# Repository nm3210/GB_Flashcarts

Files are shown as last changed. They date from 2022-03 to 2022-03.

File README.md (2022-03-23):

# GB Flashcarts

## MBC5 Short
*Uploaded to OshPark: https://oshpark.com/shared_projects/A7b5nxHa*

MBC5 Short Front in OshPark purple&nbsp;MBC5 Short Back in OshPark purple
MBC5 Short Front&nbsp;MBC5 Short Back

This is my first try (plus updates) at routing the short version of an MBC5 flashcart, there certainly wasn't a lot of room!

Heavily inspired by [**HDR**](https://martinrefseth.com/)'s [updated MBC3](https://oshpark.com/shared_projects/YCtVNv4A) cart with clean borders and neat original/OEM features like the production date squares and (totally unnecessary) fiducial markings, as well as his own older [short MBC5 cart](https://oshpark.com/shared_projects/IOwfD0lC).

### Board features

\- GameBoy_GamePak_AGB-002 template from [github.com/**djedditt**/kicad-gamepaks](https://github.com/djedditt/kicad-gamepaks) (though I had to change all the rear shapes into netted pads)

\- Schematic mostly from [github.com/**HDR**/MBC5-Flashcart](https://github.com/HDR/MBC5-Flashcart)

\- Date markings and fiducials directly from [github.com/**HDR**/MBC3-Flashcart](https://github.com/HDR/MBC3-Flashcart) (though I tweaked the size a bit)

\- Some labels done via [github.com/gregdavill/KiBuzzard](https://github.com/gregdavill/KiBuzzard)

\- No traces connecting to the cart connector pins on the back side of the board, with a ground plane buffer - this seems to be a 'feature' on a lot of the OEM MBC3/MBC5 nintendo gameboy cartidges I've seen, though I don't know why. This restricted the routing on the board quite a bit!

### Bill of Materials
*Note*: need to order at a 0.8mm service (see OshPark's ["**2oz-0.8mm**"](https://docs.oshpark.com/services/two-layer-hhdc/)) for it to actually fit in a cart slot

| Reference | Part |
| :-- | :--: |
| U1 | TSOP-40/TSOP-48 MBM29F033C-90PTN, AM29F016B-90EC, or similar |
| U2 | MBC5 (from donor cart?) |
| U3 | 28-pin SOIC FM18W08 |
| C# | 100nF Capacitor 0603 |

### Changelog
\- **v1** around 2022-03-12

&emsp;First release, hoping for the best

\- **v2** around 2022-03-22

&emsp;Change from TSOP-40 to TSOP-48 to allow for more chip variants (including ones I bought of course)

&emsp;Fixed **wrong corner** marker on U1 (from lower-left to upper-right, specifically: the side with the **W**rite**E**nable pin should be facing south)

&emsp;Minor routing updates/cleanup

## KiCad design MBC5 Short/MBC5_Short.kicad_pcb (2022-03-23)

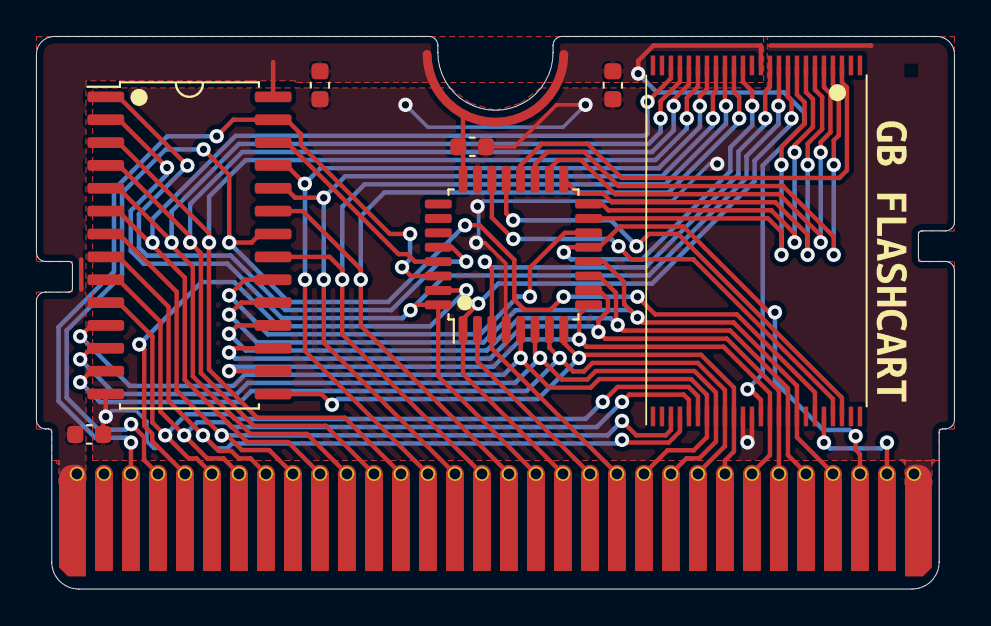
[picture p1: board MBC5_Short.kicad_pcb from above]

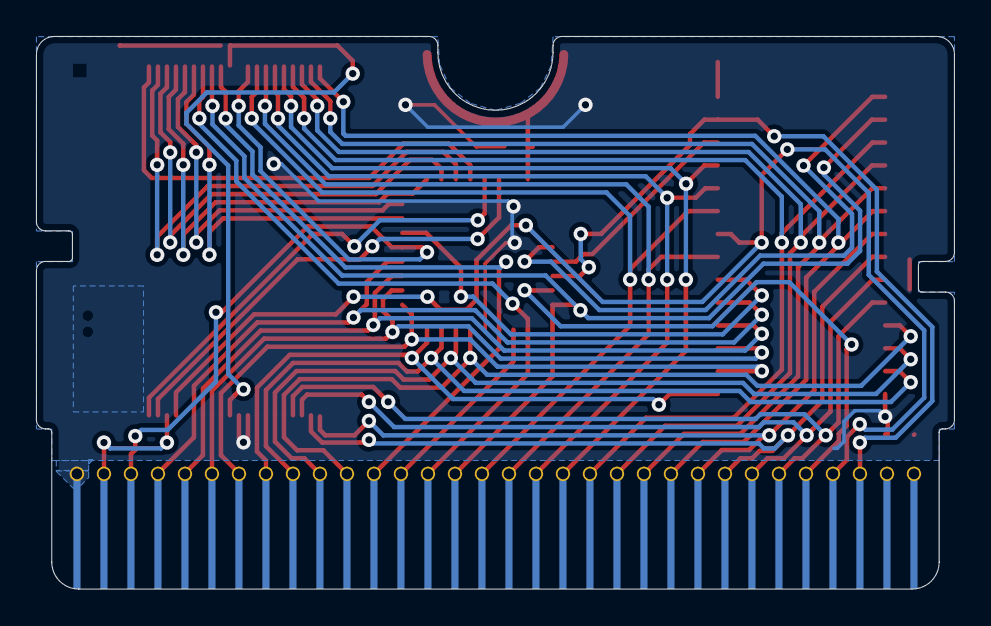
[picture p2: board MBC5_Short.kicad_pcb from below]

Board: 2 copper layers, 51.0 x 30.7 mm, 14 parts (3 on the bottom side), 42 nets.

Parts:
C1, C2, C3, C4: 100nF; C_0603_1608Metric
GNDPAD: Nintendo_2.25x2.25_Fiducial
J1: GameBoy_GamePak_AGB-002; GameBoy_GamePak_AGB-002_P1.50mm_Edge
PAD*: GB-ProductionIndicator
U1: 29F0; TSOP-I-48_18.4x12mm_P0.5mm
U2: MBC5; LQFP-32_7x7mm_P0.8mm
U3: FM18W08; SOIC-28W_7.5x17.9mm_P1.27mm
kibuzzard-622AB1EA: G***; kibuzzard-622AB1EA
kibuzzard-622AB126: G***; kibuzzard-622AB126
kibuzzard-622CFB3C: G***; kibuzzard-622CFB3C
kibuzzard-622CFB40: G***; kibuzzard-622CFB40

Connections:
+5V: C1.1, C2.1, C3.1, C4.1, J1.1, U1.11 (VCC~), U1.30 (VCC), U2.24 (PWR), U3.28 (VDD)
A0: J1.6, U1.4 (A0~), U3.10 (A0)
A1: J1.7, U1.3 (A1), U3.9 (A1)
A2: J1.8, U1.2 (A2), U3.8 (A2)
A3: J1.9, U1.1 (A3), U3.7 (A3)
A4: J1.10, U1.40 (A4), U3.6 (A4)
A5: J1.11, U1.39 (A5), U3.5 (A5)
A6: J1.12, U1.38 (A6), U3.4 (A6)
A7: J1.13, U1.37 (A7), U3.3 (A7)
A8: J1.14, U1.36 (A8), U3.25 (A8)
A9: J1.15, U1.35 (A9), U3.24 (A9)
A10: J1.16, U1.34 (A10), U3.21 (A10)
A11: J1.17, U1.33 (A11), U3.23 (A11)
A12: J1.18, U1.28 (A12), U2.32 (A12), U3.2 (A12)
A13: J1.19, U1.27 (A13), U2.1 (A13)
A14: J1.20, U2.2 (A14)
A15: J1.21, U1.29 (CE), U2.3 (A15)
AA13: U2.29 (AA13), U3.26 (A13)
AA14: U2.28 (AA14), U3.1 (A14)
CS: J1.5, U2.31 (/CS)
D0: J1.22, U1.5 (D0), U2.5 (D0), U3.11 (DQ0)
D1: J1.23, U1.6 (D1), U2.6 (D1), U3.12 (DQ1)
D2: J1.24, U1.7 (D2), U2.7 (D2), U3.13 (DQ2)
D3: J1.25, U1.8 (D3), U2.8 (D3), U3.15 (DQ3)
D4: J1.26, U1.12 (D4), U2.9 (D4), U3.16 (DQ4)
D5: J1.27, U1.13 (D5), U2.10 (D5), U3.17 (DQ5)
D6: J1.28, U1.14 (D6), U2.11 (D6), U3.18 (DQ6)
D7: J1.29, U1.15 (D7), U2.12 (D7), U3.19 (DQ7)
GND: C1.2, C2.2, C3.2, C4.2, J1.32, U1.9 (GND), U1.10 (GND), U2.4 (GND), U2.23 (GND), U3.14 (VSS)
RA14: U1.26 (A14), U2.15 (RA14)
RA15: U1.25 (A15), U2.16 (RA15)
RA16: U1.24 (A16), U2.17 (RA16)
RA17: U1.23 (A17), U2.18 (RA17)
RA18: U1.22 (A18), U2.19 (RA18)
RA19: U1.21 (A19), U2.20 (RA19)
RA20: U1.20 (A20), U2.21 (RA20)
RA21: U1.19 (A21), U2.22 (RA21)
RAMCS: U2.14 (/RAMCS), U3.20 (~CE)
RD: J1.4, U1.17 (OE~), U3.22 (~OE)
RESET: J1.30, U1.32 (RESET), U2.13 (/RESET)
WE_SND: J1.31, U1.18 (WE)
WR: J1.3, U2.30 (/WR), U3.27 (~WE)

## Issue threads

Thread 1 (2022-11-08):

Support FRAM larger than 8kb

kirkegaard, 2022-11-08:
It looks like the cart is missing the OR-gate, a cap and resistor. Do you have any plans on adding the extra components from the updated version of HDRs cart?

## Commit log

2022-02-27 Add initial MBC5 Short kicad files
    The main body has been created from the GameBoy_GamePak_AGB-002 template via https://github.com/djedditt/kicad-gamepaks.
    [MBC5_Short.kicad_pcb, MBC5_Short.kicad_sch, MBC5_Short.sch]
2022-02-28 Update MBC5 schematic properties, add title, etc.
    [MBC5_Short.kicad_sch]
2022-02-28 Add MBC5 chips (ROM, FRAM, MBC5) to schematic, not wired yet
    A few of the symbols came from HDR's https://github.com/HDR/Game-Boy-KiCad-Library, thank you thank you!!
    [MBC5_Short.kicad_sch]
2022-02-28 Add little jumper wires off each connection for ease
    [MBC5_Short.kicad_sch]
2022-02-28 Add nets between all components
    This generally, again, follows the work from HDR via https://github.com/HDR/MBC5-Flashcart/blob/29cbd084a0546ef0b45e91f31f956e2d148b7e93/MBC5%20Flashcart%20Schematic.pdf but I did try to corroborate 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
    [MBC5_Short.kicad_sch]
2022-02-28 Add unused rumble net, for curiosity
    From http://www.devrs.com/gb/files/rumble.gif.
    [MBC5_Short.kicad_sch]
2022-02-28 Add decoupling capacitors
    [MBC5_Short.kicad_sch]
2022-03-13 Remove unused old-style schematic
    [MBC5_Short.sch]
2022-03-13 Initialize PCB configuration (blank template)
    [MBC5_Short.kicad_pcb]
2022-03-13 Fix 48-pin SOP reference on schemetic with 40-pin footprint package
    I changed from the MBM29F033C which I incorrectly had associated with a TSOP-40 and swapped it with the similar AM29F032 package so the pins were all correct.
    [MBC5_Short.kicad_sch]
2022-03-13 Update GameBoy_GamePak_AGB-002 template with pads instead of just shapes
    This also copies over all the nets I was using for the pins
    [MBC5_Short.kicad_pcb]
2022-03-13 Add PCB stackup to match a generic '2oz-0.8mm' service
    ala OshPark
    [MBC5_Short.kicad_pcb]
2022-03-13 Update board specifications/clearances for OshPark service
    Even though I did all the routing with the original settings....😬
    [MBC5_Short.kicad_pcb]
2022-03-13 Route entire board, bam
    This was a lot of work, but I really didn't feel like doing micro-commits for all the changes here and there
    [MBC5_Short.kicad_pcb]
2022-03-13 Add all gerber files used for oshpark submission
    via https://oshpark.com/shared_projects/VMSFCe2c
    [MBC5_Short-B_Cu.gbr, MBC5_Short-B_Mask.gbr, MBC5_Short-B_Paste.gbr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]
2022-03-23 Change TSOP-40 to TSOP-48 to accomodate more chip variations
    [MBC5_Short.kicad_pcb]
2022-03-23 Update MBC5 Short to v2
    with updated oshpark link, images, and gerber files
    [MBC5_Short-B_Cu.gbr, MBC5_Short-B_Mask.gbr, MBC5_Short-B_Paste.gbr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]
